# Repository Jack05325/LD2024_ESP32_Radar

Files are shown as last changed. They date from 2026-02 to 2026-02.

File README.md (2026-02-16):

# LD2420 Radar ESP32

## Descrizione del Progetto

Questo progetto contiene i file di progettazione PCB per un modulo radar basato sul sensore LD2420 integrato con un microcontrollore ESP32. Il sensore LD2420 è un radar a onde millimetriche a 24GHz per il rilevamento di presenza umana, ideale per applicazioni di domotica e automazione.

### Caratteristiche Principali

- **Sensore Radar**: LD2420 a 24GHz per rilevamento preciso di presenza e movimento
- **Microcontrollore**: ESP32 con connettività WiFi e Bluetooth integrata
- **Formato PCB**: Design compatto e ottimizzato per facile integrazione
- **Output**: Dati di rilevamento elaborabili via WiFi/Bluetooth

### Contenuto del Repository

- **File KiCad**: Schema elettrico (.kicad_sch) e layout PCB (.kicad_pcb)
- **BOM**: Bill of Materials nella cartella `/bom`
- **Gerber**: File pronti per la produzione nella cartella `/gerber_to_order`
- **PDF**: Schema elettrico esportato in formato PDF
- **Backup**: Versioni precedenti del progetto in `/LD2420_Radar_ESP32-backups`

### Software Richiesto

- KiCad 7.0 o superiore per aprire e modificare i file di progetto

### Note di Produzione

I file Gerber pronti per l'ordine sono disponibili nella cartella `gerber_to_order`. Consultare il PDF dello schema per i dettagli sul circuito.

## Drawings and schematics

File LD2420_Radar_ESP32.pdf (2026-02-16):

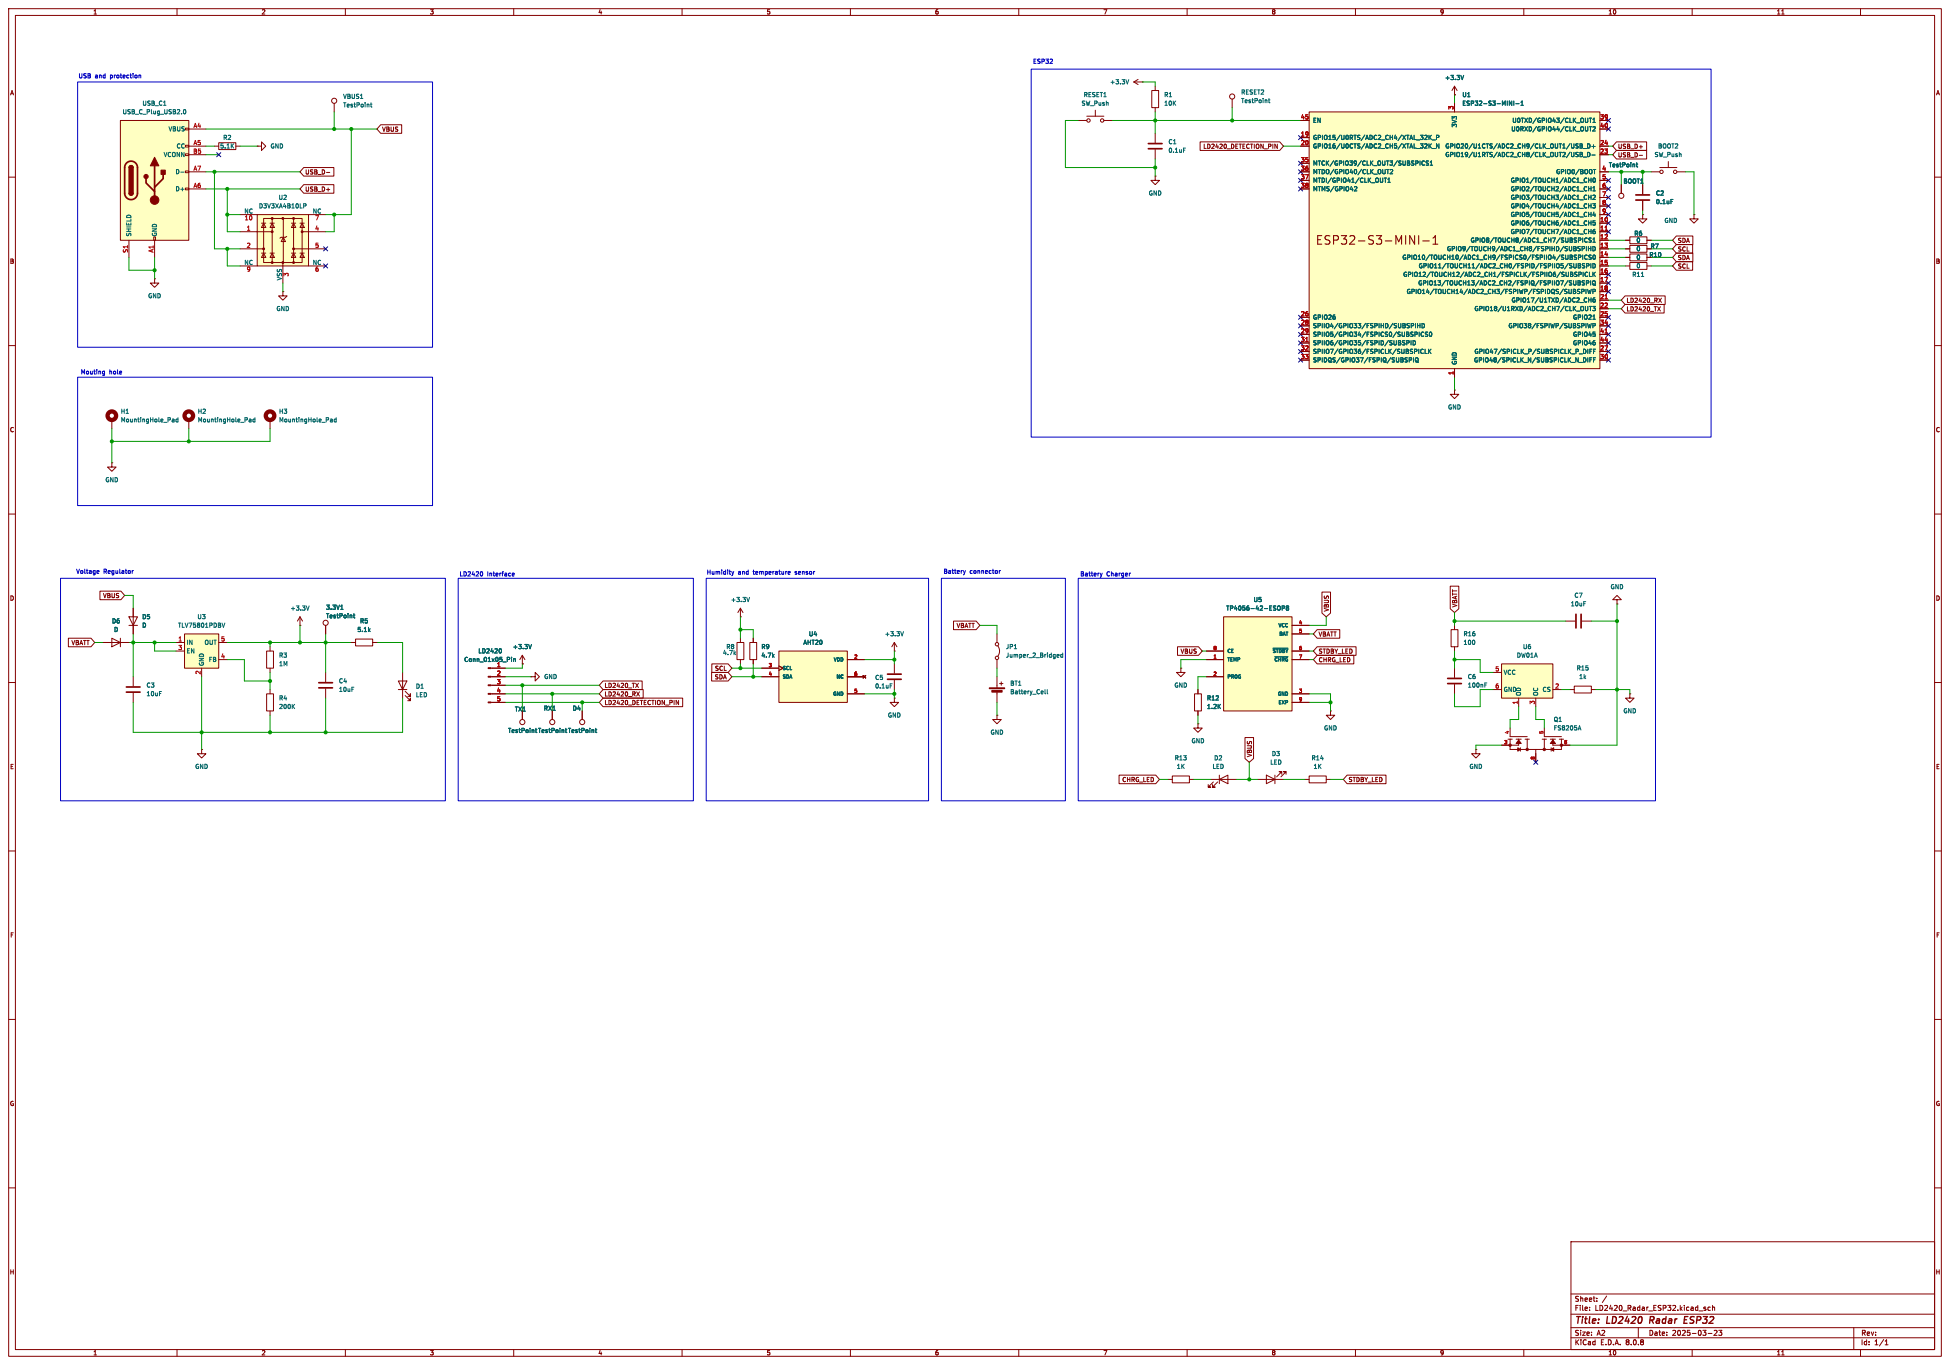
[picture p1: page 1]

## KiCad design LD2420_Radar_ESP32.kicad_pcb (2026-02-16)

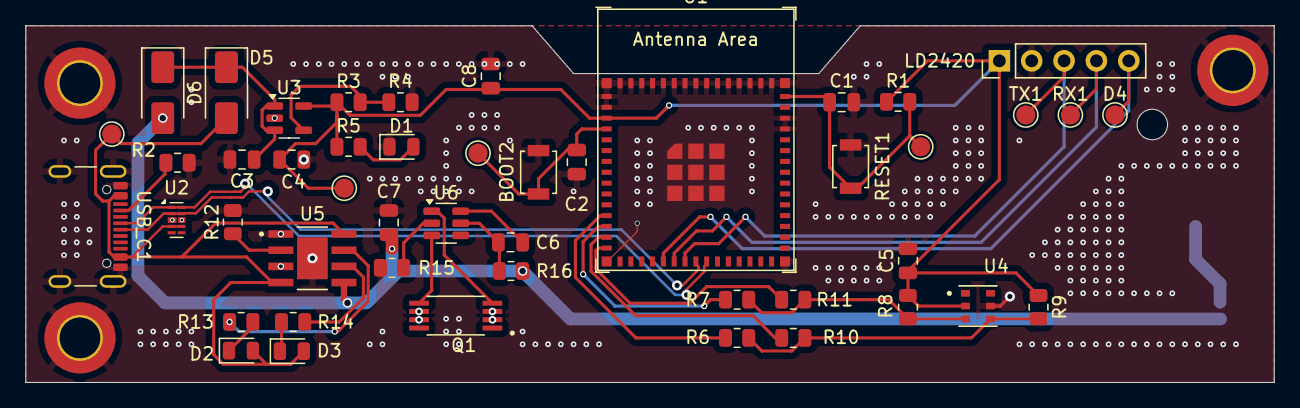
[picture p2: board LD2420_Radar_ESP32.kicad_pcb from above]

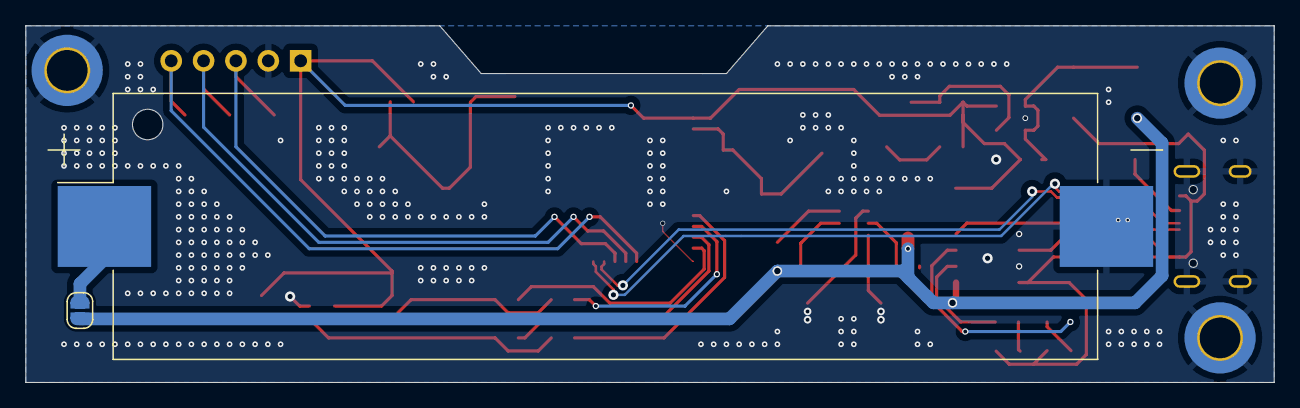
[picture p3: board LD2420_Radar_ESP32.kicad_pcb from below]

Board: 2 copper layers, 98.0 x 28.0 mm, 52 parts (2 on the bottom side), 32 nets.

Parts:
3.3V1: TestPoint; TestPoint_Pad_D1.5mm
BOOT1: TestPoint; TestPoint_Pad_D1.5mm
BOOT2: SW_Push; SW_SPST_B3U-1000P
BT1: Battery_Cell; BatteryHolder_Keystone_1042_1x18650
C1, C2, C5: 0.1uF; C_0805_2012Metric
C3, C4, C7, C8: 10uF; C_0805_2012Metric
C6: 100nF; C_0805_2012Metric
D1, D2, D3: LED; LED_0805_2012Metric
D4: TestPoint; TestPoint_Pad_D1.5mm
D5, D6: D; D_SMA
H1, H2, H3: MountingHole_Pad; MountingHole_3.2mm_M3_DIN965_Pad_TopBottom
JP1: Jumper_2_Open; SolderJumper-2_P1.3mm_Open_RoundedPad1.0x1.5mm
LD2420: Conn_01x05_Pin; PinHeader_1x05_P2.54mm_Vertical
Q1: FS8205A; SOP65P640X120-8N
R1: 10K; R_0805_2012Metric
R2: 5.1K; R_0805_2012Metric
R3: 1M; R_0805_2012Metric
R4: 200K; R_0805_2012Metric
R5: 5.1k; R_0805_2012Metric
R6, R7, R10, R11: 0; R_0805_2012Metric
R8, R9: 4.7k; R_0805_2012Metric
R12: 1.2K; R_0805_2012Metric
R13, R14: 1K; R_0805_2012Metric
R15: 1k; R_0805_2012Metric
R16: 100; R_0805_2012Metric
RESET1: SW_Push; SW_SPST_B3U-1000P
RESET2: TestPoint; TestPoint_Pad_D1.5mm
RX1: TestPoint; TestPoint_Pad_D1.5mm
TX1: TestPoint; TestPoint_Pad_D1.5mm
U1: ESP32-S3-MINI-1
U2: D3V3XA4B10LP; Diodes_UDFN-10_1.0x2.5mm_P0.5mm
U3: TLV75801PDBV; SOT-23-5
U4: AHT20; PSON100P300X300X110-6N
U5: TP4056-42-ESOP8; SOIC127P600X175-9N
U6: DW01A; SOT-23-6
USB_C1: USB_C_Plug_USB2.0; USB_C_Receptacle_GCT_USB4105-xx-A_16P_TopMnt_Horizontal
VBUS1: TestPoint; TestPoint_Pad_D1.5mm

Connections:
+3.3V: 3.3V1.1, C4.1, C5.1, C8.1, LD2420.1, R1.1, R3.1, R5.1, R8.1, R9.1, U1.3 (3V3), U3.5 (OUT), U4.2 (VDD)
CHRG_LED: R13.2, U5.7 (~CHRG)
GND: BOOT2.2, BT1.2 (-), C1.2, C2.2, C3.2, C4.2, C5.2, C7.1, C8.2, D1.1 (K), H1.1, H2.1, H3.1, LD2420.2, Q1.2, Q1.3, Q1.6, Q1.7, R2.2, R4.2, R12.2, R15.2, RESET1.1, U1.1 (GND), U1.2 (GND), U1.42 (GND), U1.43 (GND), U1.46 (GND), U1.47 (GND), U1.48 (GND), U1.49 (GND), U1.50 (GND), U1.51 (GND), U1.52 (GND), U1.53 (GND), U1.54 (GND), U1.55 (GND), U1.56 (GND), U1.57 (GND), U1.58 (GND), U1.59 (GND), U1.60 (GND), U1.61 (GND), U1.62 (GND), U1.63 (GND), U1.64 (GND), U1.65 (GND), U2.3 (VSS), U2.8 (VSS), U3.2 (GND), U4.5 (GND), U5.1 (TEMP), U5.3 (GND), U5.9 (EXP), USB_C1.A1 (GND), USB_C1.A12 (GND), USB_C1.B1 (GND), USB_C1.B12 (GND), USB_C1.S1 (SHIELD)
LD2420_DETECTION_PIN: D4.1, LD2420.5, U1.20 (GPIO16/U0CTS/ADC2_CH5/XTAL_32K_N)
LD2420_RX: LD2420.4, RX1.1, U1.21 (GPIO17/U1TXD/ADC2_CH6)
LD2420_TX: LD2420.3, TX1.1, U1.22 (GPIO18/U1RXD/ADC2_CH7/CLK_OUT3)
unnamed: BT1.1 (+), JP1.2 (B)
unnamed: D1.2 (A), R5.2
unnamed: D2.1 (K), R13.1
unnamed: D3.1 (K), R14.2
unnamed: C3.1, D5.1 (K), D6.1 (K), U3.1 (IN), U3.3 (EN)
unnamed: C1.1, R1.2, RESET1.2, RESET2.1, U1.45 (EN)
unnamed: BOOT1.1, BOOT2.1, C2.1, U1.4 (GPIO0/BOOT)
unnamed: R6.1, U1.12 (GPIO8/TOUCH8/ADC1_CH7/SUBSPICS1)
unnamed: R7.1, U1.13 (GPIO9/TOUCH9/ADC1_CH8/FSPIHD/SUBSPIHD)
unnamed: R10.1, U1.14 (GPIO10/TOUCH10/ADC1_CH9/FSPICS0/FSPIIO4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)
unnamed: R11.1, U1.15 (GPIO11/TOUCH11/ADC2_CH0/FSPID/FSPIIO5/S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)
unnamed: R3.2, R4.1, U3.4 (FB)
unnamed: R12.1, U5.2 (PROG)
unnamed: R15.1, U6.2 (CS)
unnamed: C6.2, U6.6 (GND)
unnamed: Q1.5, U6.3 (OC)
unnamed: Q1.4, U6.1 (OD)
unnamed: C6.1, R16.2, U6.5 (VCC)
unnamed: R2.1, USB_C1.A5 (CC)
SCL: R7.2, R8.2, R11.2, U4.3 (SCL)
SDA: R6.2, R9.2, R10.2, U4.4 (SDA)
STDBY_LED: R14.1, U5.6 (~STDBY)
USB_D+: U1.24 (GPIO20/U1CTS/ADC2_CH9/CLK_OUT1/USB_D+), U2.1, U2.10 (NC), USB_C1.A6 (D+)
USB_D-: U1.23 (GPIO19/U1RTS/ADC2_CH8/CLK_OUT2/USB_D-), U2.2, U2.9 (NC), USB_C1.A7 (D-)
VBATT: C7.2, D6.2 (A), JP1.1 (A), R16.1, U5.5 (BAT)
VBUS: D2.2 (A), D3.2 (A), D5.2 (A), U2.4, U2.7 (NC), U5.4 (VCC), U5.8 (CE), USB_C1.A4 (VBUS), USB_C1.A9 (VBUS), USB_C1.B4 (VBUS), USB_C1.B9 (VBUS), VBUS1.1

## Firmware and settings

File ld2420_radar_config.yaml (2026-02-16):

esphome:
  name: ld2420_radar
  platformio_options:
    build_flags: 
      -DARDUINO_USB_CDC_ON_BOOT=1
      -DARDUINO_USB_MODE=1
  on_boot:
    priority: -100
    then:
      - logger.log: "Boot completato in modalità sicura"

esp32:
  board: esp32-s3-devkitc-1
  variant: esp32s3
  framework:
    type: arduino

wifi:
  ssid: !secret ssid
  password: !secret wifi_psw

ota:
  - platform: esphome
    password: !secret ota_psw

api:
  encryption:
    key: "tD4JJkO0P1YAfMLdvpjBFxyPb4QR+PrrIR6dX85RqXE="

web_server:
  port: 80
  auth:
    username: admin
    password: "admin"

logger:
  baud_rate: 115200

deep_sleep:
  id: deep_sleep_1
  run_duration: 10s         # tempo in cui resta sveglio per leggere/sincronizzare
  sleep_duration: 30s       # si ri-sveglia comunque ogni 30 secondi
  wakeup_pin:
    number: GPIO16          # pin esterno che può risvegliare anche prima del timer
  wakeup_pin_mode: INVERT_WAKEUP


uart:
  id: ld2420_uart
  tx_pin: GPIO17   # ESP32 → LD2420_RX
  rx_pin: GPIO18   # ESP32 ← LD2420_TX
  baud_rate: 115200
  parity: NONE
  stop_bits: 1

ld2420:
  uart_id: ld2420_uart

i2c:
  sda: 10
  scl: 11
  scan: true
  id: bus_a

text_sensor:
  - platform: ld2420
    fw_version:
      name: Versione firmware

sensor:
  - platform: ld2420
    moving_distance:
      name: Distanza di movimento
  
  - platform: aht10
    variant: AHT20
    i2c_id: bus_a
    temperature:
      name: "Temperature"
    humidity:
      name: "Humidity"
    update_interval: 10s

binary_sensor:
  - platform: ld2420
    has_target:
      name: Presenza

  #- platform: gpio
  #  pin:
  #    number: GPIO16
  #    mode: INPUT_PULLUP
  #  name: "Stato GPIO16"
  #  id: "deep_sleep_pin"
  #  device_class: opening

switch:
  - platform: restart
    name: Riavvio nodo ESPHome

select:
  - platform: ld2420
    operating_mode:
      name: Modalità operativa

number:
  - platform: ld2420
    presence_timeout:
      name: Timeout di rilevazione presenza
    min_gate_distance:
      name: Distanza minima gate
    max_gate_distance:
      name: Distanza massima gate
    gate_select:
      name: Selezione gate
    still_threshold:
      name: Impostazione soglia immobilità
    move_threshold:
      name: Impostazione soglia movimento

button:
  - platform: ld2420
    apply_config:
      name: Applica configurazione
    factory_reset:
      name: Reset a impostazioni di fabbrica
    restart_module:
      name: Riavvio modulo
    revert_config:
      name: Undo modifiche
